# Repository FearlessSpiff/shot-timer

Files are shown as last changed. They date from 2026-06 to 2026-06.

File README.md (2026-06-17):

# shot-timer

Switch-controlled coffee shot timer for the Seeed XIAO nRF52840 with SSD1306 OLED display and deep sleep.

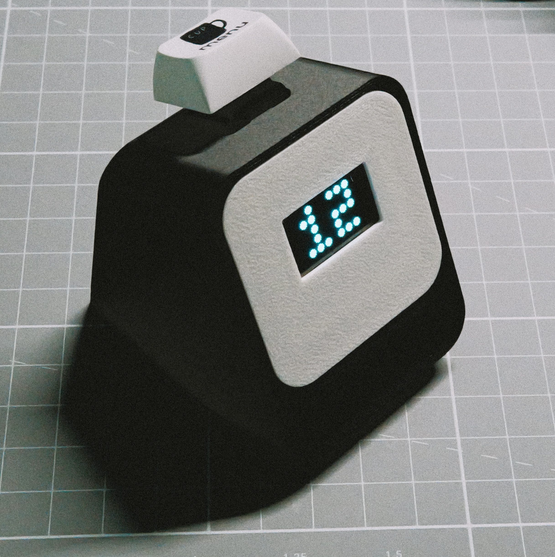
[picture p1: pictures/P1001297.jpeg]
Shot timer


## IMPORTANT

* Rotate case by 115.20 degrees in the slicer to have a nice front plate
* Rotate the backpanel by 79.8 degrees to make it sit flat on the bed

## Wiring

```
 Seeed XIAO nRF52840
 ┌─────────────────────┐
 │                 3V3 ├─────────────────── VCC ──┐
 │                 GND ├──────────┬──────── GND   ├── SSD1306
 │         D4 / (SDA)  ├──────────│──────── SDA   │    OLED
 │         D5 / (SCL)  ├──────────│──────── SCL ──┘
 │                  D1 ├───[ A ]  │
 │                BAT+ ├─────│────│──────────────── Battery +
 │                BAT- ├─────│────│──────────────── Battery -
 └─────────────────────┘     │    │
                             │    │
                          ┌──┴──┐ │
                          │ SW  │ │
                          └──┬──┘ │
                           [ B ]  │
                             └────┘ (GND)

 No external resistor needed — internal pull-up on D1 is enabled in firmware.
 Battery charges automatically when USB is connected.
```

| XIAO pin | Connects to |
|---|---|
| `3V3` | OLED VCC |
| `GND` | OLED GND, Switch Leg B |
| `D4 (SDA)` | OLED SDA |
| `D5 (SCL)` | OLED SCL |
| `D1` | Switch Leg A |
| `BAT+` | Battery positive |
| `BAT-` | Battery negative |

Most SSD1306 breakout boards label their pins `VCC GND SCL SDA` left-to-right — double check yours before wiring.

> [!WARNING]
> Use `3V3` for OLED power, **not** `VUSB`. VUSB is only live when USB is connected — the OLED will be dead on battery if wired to VUSB.

## Behaviour

| Action | Result |
|---|---|
| Short press (stopped) | Start timer |
| Short press (running) | Pause timer |
| Hold 1 s | Reset timer to 0 |
| Hold 3 s | Show battery percentage (2 s), then back to the timer |
| Timer reaches 99 s | Deep sleep |
| Paused / stopped for 60 s | Deep sleep |

Battery percentage is read from the XIAO nRF52840 Sense's onboard divider (`P0.14`/`VBAT_ENABLE` gates `P0.31`/`PIN_VBAT`) — no extra wiring needed beyond the `BAT+`/`BAT-` connection already shown above.

Press the switch to wake from deep sleep.

## Case

* The case has been adapted from <https://makerworld.com/en/models/1393341-desktop-wifi-informer-esp8266-oled-ssd1306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>
* Seeed XIAO BLE compatability has been added
* My SSD1306 has been made compatible to the front panel
* A hole has been added on top to take an MX switch

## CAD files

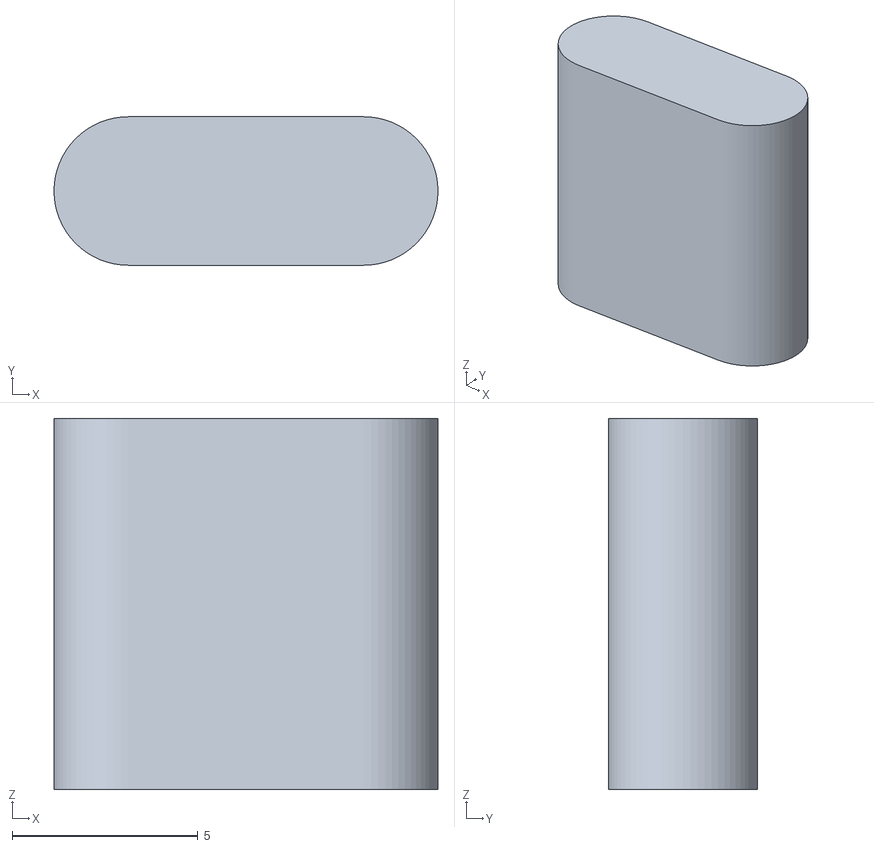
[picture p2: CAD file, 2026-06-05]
case/helper/usbc-cutout-gauge.stl
10.3 x 4.00 x 10.0

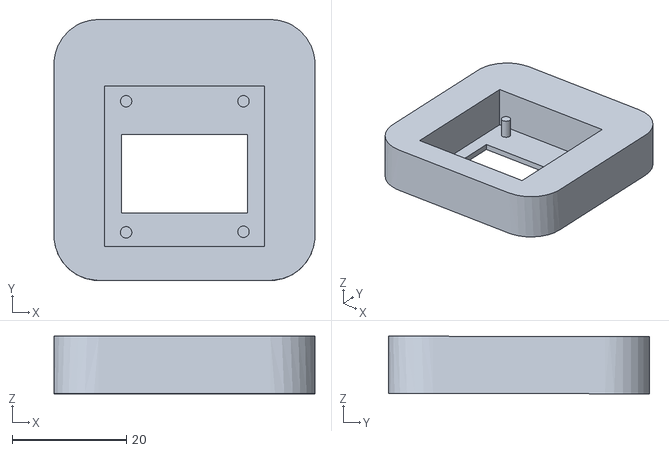
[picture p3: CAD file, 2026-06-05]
case/shot-timer-frontplate.stl
45.6 x 45.6 x 10.1

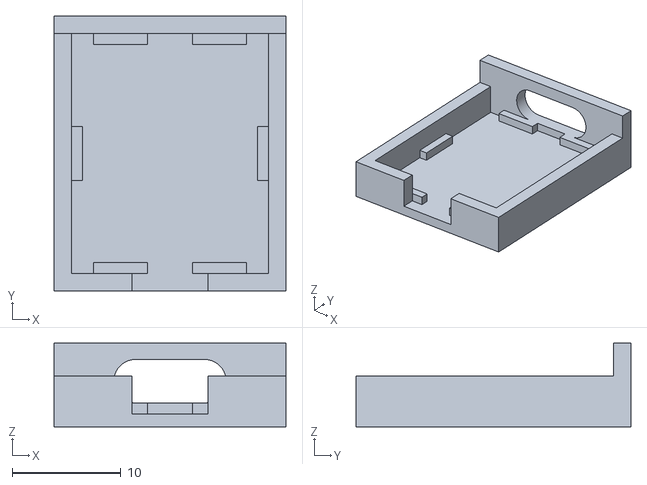
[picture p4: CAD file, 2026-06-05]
case/helper/xiao-tub.stl
21.3 x 25.3 x 7.70

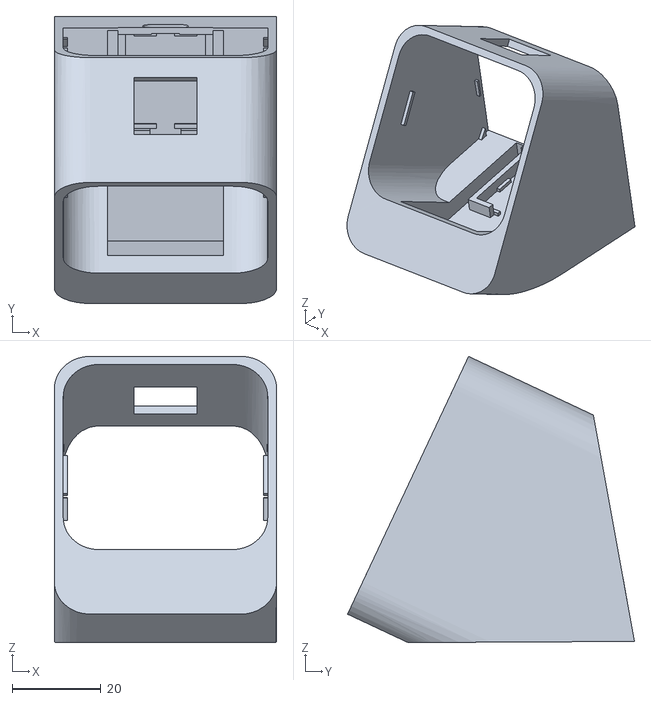
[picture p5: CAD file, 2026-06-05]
case/shot-timer-case.stl
50.0 x 64.5 x 64.4

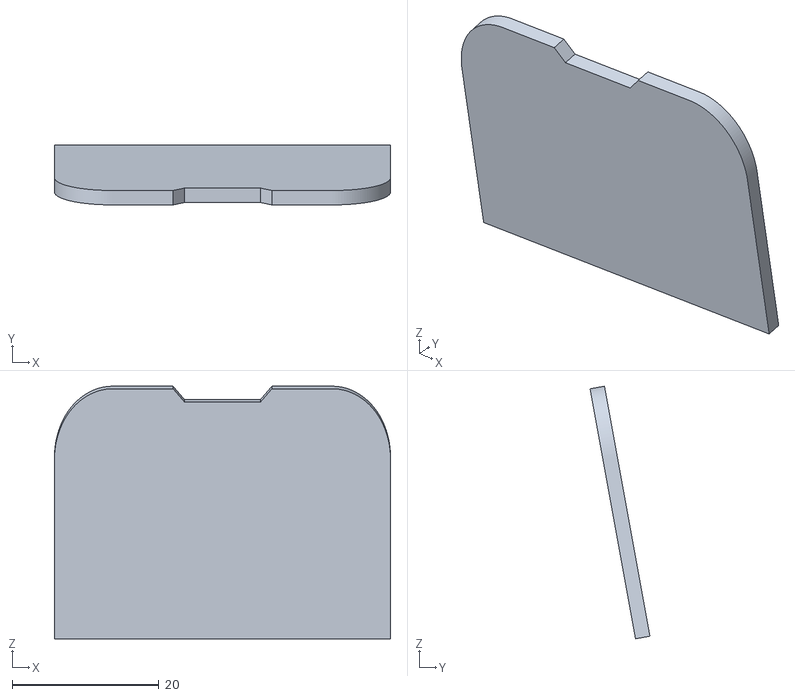
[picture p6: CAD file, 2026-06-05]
case/shot-timer-backplate.stl
45.8 x 8.16 x 34.4

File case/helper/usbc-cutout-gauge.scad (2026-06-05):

// ============================================================
//  USB-C Cutout Gauge
//  Matches the oval hole cut in xiao-tub.scad exactly.
//  Print this to verify the cutout fits your USB-C connector
//  before printing the full tub.
//
//  Dimensions (from xiao-tub.scad):
//    Width:  usbc_hole_w = 8.94 + 1.4 = 10.34 mm
//    Height: usbc_conn_h = 4.00 mm  (radius = 2.00 mm)
//    Shape:  stadium (hull of two circles)
// ============================================================

// Mirror of xiao-tub.scad values — keep in sync if tub changes
usbc_conn_w  = 8.94;
usbc_conn_h  = 4;
usbc_hole_r  = usbc_conn_h / 2;
usbc_hole_w  = usbc_conn_w + 1.4;

gauge_depth  = 10.0;   // extrusion thickness of the gauge

linear_extrude(height = gauge_depth)
    hull() {
        translate([ usbc_hole_w/2 - usbc_hole_r, 0])
            circle(r = usbc_hole_r, $fn = 64);
        translate([-(usbc_hole_w/2 - usbc_hole_r), 0])
            circle(r = usbc_hole_r, $fn = 64);
    }

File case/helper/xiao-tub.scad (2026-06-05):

// ============================================================
//  Seeed XIAO nRF52840 — MCU Tub / Cradle
//  Separate part to position freely alongside body.scad
//
//  Board dimensions (official):
//    PCB:       21.5 mm (L) × 17.5 mm (W) × 1.0 mm (thick)
//    Total H:   ~3.5 mm incl. components on top
//    USB-C:     on the +Y short end
//               connector body: 8.94 mm wide × 3.26 mm tall
//
//  Tub orientation:
//    X = width  (17.5 mm direction)
//    Y = length (21.5 mm, USB-C end at +Y)
//    Z = height (opens upward, board drops in from top)
// ============================================================

// --- Board dimensions ---
board_l       = 21.5;   // PCB length  (Y)
board_w       = 17.5;   // PCB width   (X)
board_h       = 1.0;    // PCB thickness
comp_h        = 2.5;    // tallest components above PCB (excl. USB-C)
tol           = 0.3;    // clearance around board on each side

// --- Tub wall & floor (defined early so other vars can use them) ---
wall          = 1.6;    // wall thickness
floor_t       = 1.2;    // floor thickness

// --- USB-C connector geometry ---
usbc_conn_w   = 8.94;              // connector width (IEC spec)
usbc_conn_h   = 4;             // connector height (typical SMD receptacle)
usbc_hole_r   = usbc_conn_h / 2;  // end radius fixed to connector height → keeps oval shape
usbc_hole_w   = usbc_conn_w + 1.4; // +1.4 mm total clearance
usbc_hole_h   = usbc_conn_h + 1.9; // +1.9 mm total clearance
// Z-center of connector measured from tub floor:
usbc_center_z = floor_t + board_h + usbc_conn_h / 2;
// Front wall height: floor + PCB + connector + 1.5 mm margin
front_wall_h  = floor_t + board_h + usbc_conn_h + 1.5;

// --- Battery solder cutout (-Y back wall) ---
batt_w        = 7.0;   // width — covers BAT+/BAT- pads
batt_h        = 3.5;   // height — clears PCB + some room
batt_z        = floor_t; // starts at tub floor level

// --- Derived internals ---
inner_l   = board_l + 2 * tol;
inner_w   = board_w + 2 * tol;
inner_h   = board_h + comp_h;

outer_l   = inner_l + 2 * wall;
outer_w   = inner_w + 2 * wall;
outer_h   = floor_t + inner_h;   // height of back/side walls (open top)

// --- Ledge parameters ---
ledge_t   = 1.0;   // protrusion into pocket
ledge_h   = board_h;
ledge_len = 5.0;
corner_gap = 2.0;

module xiao_tub() {
    difference() {
        union() {
            // Base box (back + side walls at normal height)
            cube([outer_w, outer_l, outer_h]);

            // Raised front wall (+Y) to enclose USB-C connector
            translate([0, outer_l - wall, 0])
                cube([outer_w, wall, front_wall_h]);
        }

        // --- Inner pocket ---
        translate([wall, wall, floor_t])
            cube([inner_w, inner_l, inner_h + 1]);

        // --- USB-C oval hole in raised front wall ---
        // rotate([90,0,0]) maps +Z → -Y, so starting at outer_l+1 cuts back through the wall
        translate([outer_w / 2, outer_l + 1, usbc_center_z])
            rotate([90, 0, 0])
                linear_extrude(height = wall + 3)
                    hull() {
                        translate([ usbc_hole_w/2 - usbc_hole_r, 0])
                            circle(r = usbc_hole_r, $fn = 64);
                        translate([-(usbc_hole_w/2 - usbc_hole_r), 0])
                            circle(r = usbc_hole_r, $fn = 64);
                    }

        // --- Battery solder cutout on -Y (back) wall ---
        translate([(outer_w - batt_w) / 2, -0.01, batt_z])
            cube([batt_w, wall + 2, batt_h]);
    }

    // --- Board retaining ledges (all four sides) ---
    // -Y wall (back) — two ledges either side of battery cutout
    translate([wall + corner_gap, wall, floor_t])
        cube([ledge_len, ledge_t, ledge_h]);
    translate([wall + inner_w - corner_gap - ledge_len, wall, floor_t])
        cube([ledge_len, ledge_t, ledge_h]);

    // +Y wall (front) — two ledges either side of USB-C hole
    translate([wall + corner_gap, wall + inner_l - ledge_t, floor_t])
        cube([ledge_len, ledge_t, ledge_h]);
    translate([wall + inner_w - corner_gap - ledge_len, wall + inner_l - ledge_t, floor_t])
        cube([ledge_len, ledge_t, ledge_h]);

    // -X wall (left) — one ledge centered
    translate([wall, wall + (inner_l - ledge_len) / 2, floor_t])
        cube([ledge_t, ledge_len, ledge_h]);

    // +X wall (right) — one ledge centered
    translate([wall + inner_w - ledge_t, wall + (inner_l - ledge_len) / 2, floor_t])
        cube([ledge_t, ledge_len, ledge_h]);
}

xiao_tub();

// ============================================================
//  Usage:
//    use <xiao_tub.scad>
//    translate([X,Y,Z]) rotate([RX,RY,RZ]) xiao_tub();
//
//  Key dimensions:
//    Outer (back/sides): outer_w × outer_l × outer_h  ≈ 21.7 × 25.3 × 4.7 mm
//    Front wall height:  front_wall_h                 ≈ 6.7 mm
//    Inner pocket:       inner_w × inner_l            ≈ 18.1 × 22.1 mm
//    USB-C hole:         9.34 × 3.66 mm oval, centered on connector
//    Battery cutout:     7.0 × 3.5 mm, centered, -Y wall
// ============================================================

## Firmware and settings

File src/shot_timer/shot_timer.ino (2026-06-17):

/**
 * shot_timer.ino
 * Seeed XIAO nRF52840 — Switch-controlled stopwatch with deep sleep
 *
 * Wiring:
 *   Switch leg A → D1 (P0.03)
 *   Switch leg B → GND
 *   (Internal pull-up enabled — no external resistor needed)
 *
 * Behaviour:
 *   Single press (while stopped) → Start timer
 *   Single press (while running) → Pause timer
 *   Hold 1 s                     → Reset timer to 0
 *   Hold 3 s                     → Show battery percentage
 *   Timer reaches 99 s           → Deep sleep
 *   Timer paused for > 60 s      → Deep sleep
 */

#include <Arduino.h>
#include <Adafruit_GFX.h>
#include <Adafruit_SSD1306.h>

// ── Pin ──────────────────────────────────────────────────────────────
#define SWITCH_PIN    1        // D1 / P0.03

// ── OLED ─────────────────────────────────────────────────────────────
#define OLED_WIDTH   128
#define OLED_HEIGHT   64
#define OLED_RESET    -1
#define OLED_ADDRESS  0x3C

Adafruit_SSD1306 oled(OLED_WIDTH, OLED_HEIGHT, &Wire, OLED_RESET);

// ── Config ───────────────────────────────────────────────────────────
#define SHOW_SPLASH         1    // 1 = show coffee bean splash on boot, 0 = skip

// ── Timing constants ─────────────────────────────────────────────────
#define DEBOUNCE_MS         20
#define HOLD_RESET_MS     1000   // hold duration to trigger reset
#define HOLD_BATTERY_MS   3000   // hold duration to show battery percentage
#define DISPLAY_INTERVAL_MS 1000 // display update interval while running
#define MAX_SECONDS         60   // sleep when timer hits this
#define IDLE_SLEEP_MS    60000UL // sleep if paused/stopped for this long
#define BATTERY_DISPLAY_MS 2000  // how long the battery % stays on screen

// ── Battery (XIAO nRF52840 Sense onboard divider — P0.14 / P0.31) ────
// VBAT_ENABLE and PIN_VBAT are provided by the board variant.
#define VBAT_DIVIDER_RATIO (1510.0f / 510.0f)  // onboard divider ratio
#define VBAT_MV_PER_LSB    (0.003395996f)      // 10-bit ADC, ~3.6V internal ref
#define VBAT_MIN_V         3.0f                // maps to 0%
#define VBAT_MAX_V         4.2f                // maps to 100%

// ── State machine ─────────────────────────────────────────────────────
enum TimerState { STOPPED, RUNNING, PAUSED };
TimerState timerState = STOPPED;

// ── Counters & timestamps ─────────────────────────────────────────────
uint32_t elapsedSeconds  = 0;
uint32_t runStartMs      = 0;
uint32_t lastDisplayMs   = 0;
uint32_t idleStartMs     = 0;

// ── Coffee bean splash bitmap (64×64, centred on 128×64 display) ─────
static const uint8_t COFFEE_BITMAP[] = {
  0x00, 0x00, 0x00, 0x00, 0x00, 0x00, 0x00, 0x00,
  0x00, 0x00, 0x00, 0x00, 0x00, 0x00, 0x00, 0x00,
  0x00, 0x00, 0x00, 0x00, 0x00, 0x00, 0x00, 0x00,
  0x00, 0x00, 0x00, 0x00, 0x00, 0x00, 0x00, 0x00,
  0x00, 0x00, 0x00, 0x00, 0x00, 0x00, 0x00, 0x00,
  0x00, 0x00, 0x00, 0x00, 0x00, 0x00, 0x00, 0x00,
  0x00, 0x00, 0x00, 0x00, 0x00, 0x00, 0x00, 0x00,
  0x00, 0x00, 0x00, 0x00, 0x00, 0x00, 0x00, 0x00,
  0x00, 0x00, 0x00, 0x00, 0x00, 0x00, 0x00, 0x00,
  0x00, 0x00, 0x00, 0x00, 0x00, 0x00, 0x00, 0x00,
  0x00, 0x00, 0x00, 0x7F, 0x00, 0x00, 0x00, 0x00,
  0x00, 0x00, 0x01, 0xFF, 0xF0, 0x00, 0x00, 0x00,
  0x00, 0x00, 0x07, 0xFF, 0xFC, 0x00, 0x00, 0x00,
  0x00, 0x00, 0x03, 0xFF, 0xFF, 0x00, 0x00, 0x00,
  0x00, 0x00, 0x01, 0xFF, 0xFF, 0x80, 0x00, 0x00,
  0x00, 0x00, 0x10, 0xFF, 0xFF, 0xC0, 0x00, 0x00,
  0x00, 0x00, 0x18, 0x7F, 0xFF, 0xE0, 0x00, 0x00,
  0x00, 0x00, 0x1C, 0x3F, 0xFF, 0xF0, 0x00, 0x00,
  0x00, 0x00, 0x1F, 0x03, 0xFF, 0xF8, 0x00, 0x00,
  0x00, 0x00, 0x1F, 0x80, 0x07, 0xF8, 0x00, 0x00,
  0x00, 0x00, 0x1F, 0xE0, 0x01, 0xFC, 0x00, 0x00,
  0x00, 0x00, 0x0F, 0xFF, 0xF0, 0x7C, 0x00, 0x00,
  0x00, 0x00, 0x0F, 0xFF, 0xFC, 0x3C, 0x00, 0x00,
  0x00, 0x00, 0x07, 0xFF, 0xFF, 0x1C, 0x00, 0x00,
  0x00, 0x00, 0x03, 0xFF, 0xFF, 0x8C, 0x00, 0x00,
  0x00, 0x00, 0x01, 0xFF, 0xFF, 0xC0, 0x00, 0x00,
  0x00, 0x3F, 0xC0, 0xFF, 0xFF, 0xE0, 0x00, 0x00,
  0x00, 0x1F, 0xF0, 0x7F, 0xFF, 0xF0, 0x00, 0x00,
  0x00, 0x0F, 0xFC, 0x1F, 0xFF, 0xE0, 0x00, 0x00,
  0x00, 0x83, 0xFE, 0x03, 0xFF, 0x80, 0x00, 0x00,
  0x01, 0xE1, 0xFF, 0x00, 0x18, 0x00, 0x00, 0x00,
  0x01, 0xF0, 0xFF, 0x80, 0x00, 0x03, 0xF0, 0x00,
  0x01, 0xF8, 0x7F, 0x80, 0x00, 0x1F, 0xF8, 0x00,
  0x01, 0xFC, 0x7F, 0xC0, 0x00, 0x7F, 0xF8, 0x00,
  0x01, 0xFE, 0x3F, 0xE0, 0x01, 0xFF, 0xF1, 0x00,
  0x01, 0xFE, 0x3F, 0xE0, 0x03, 0xFF, 0xF1, 0x80,
  0x01, 0xFF, 0x3F, 0xF0, 0x07, 0xFF, 0xE3, 0x80,
  0x01, 0xFF, 0x3F, 0xF0, 0x0F, 0xFF, 0xC7, 0x80,
  0x00, 0xFF, 0x1F, 0xF0, 0x1F, 0xFF, 0xC7, 0x80,
  0x00, 0xFF, 0x9F, 0xF0, 0x3F, 0xFF, 0x8F, 0x80,
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
};

// ── Forward declarations ──────────────────────────────────────────────
void updateDisplay();

// ── Switch state ──────────────────────────────────────────────────────
bool     lastSwitchPhysical = HIGH;
bool     switchPressed      = false;
bool     switchHeld         = false;
bool     batteryShown       = false;
bool     buttonDown         = false;
uint32_t pressStartMs       = 0;

// ─────────────────────────────────────────────────────────────────────
// Deep sleep — wakes on switch press (falling edge on pin D1)
// ─────────────────────────────────────────────────────────────────────
void goToDeepSleep() {
  oled.ssd1306_command(SSD1306_DISPLAYOFF);

  // Wait for the switch to be released before arming GPIO SENSE —
  // otherwise the pin is already LOW and the chip wakes immediately.
  pinMode(SWITCH_PIN, INPUT_PULLUP);
  while (digitalRead(SWITCH_PIN) == LOW) {}
  delay(200);  // debounce

#ifdef NRF52_SERIES
  attachInterrupt(digitalPinToInterrupt(SWITCH_PIN), [](){}, FALLING);
  nrf_gpio_cfg_sense_input(
      g_ADigitalPinMap[SWITCH_PIN],
      NRF_GPIO_PIN_PULLUP,
      NRF_GPIO_PIN_SENSE_LOW);
  sd_power_system_off();
  NRF_POWER->SYSTEMOFF = 1;
  while (true) {}
#else
  while (true) { delay(1000); }
#endif
}

// ─────────────────────────────────────────────────────────────────────
// Reset the timer (does not change run state)
// ─────────────────────────────────────────────────────────────────────
void resetTimer() {
  elapsedSeconds = 0;
  runStartMs     = millis();
  lastDisplayMs  = millis();
  idleStartMs    = millis();
  updateDisplay();
}

// ─────────────────────────────────────────────────────────────────────
// Current total seconds (elapsed + in-progress segment)
// ─────────────────────────────────────────────────────────────────────
uint32_t currentSeconds() {
  if (timerState == RUNNING) {
    return elapsedSeconds + (millis() - runStartMs) / 1000;
  }
  return elapsedSeconds;
}

// ─────────────────────────────────────────────────────────────────────
// 3×5 dot-matrix font
// Each row byte: bit 2 = left col, bit 1 = mid col, bit 0 = right col
// ─────────────────────────────────────────────────────────────────────
#define DOT_PITCH   12   // dot center-to-center (px)
#define DOT_RADIUS   4   // dot radius (px)
#define CHAR_GAP    12   // gap between characters (px) — matches DOT_PITCH

static const uint8_t DOT_GLYPHS[10][5] = {
  {0b111, 0b101, 0b101, 0b101, 0b111},  // 0
  {0b010, 0b110, 0b010, 0b010, 0b111},  // 1
  {0b111, 0b001, 0b111, 0b100, 0b111},  // 2
  {0b111, 0b001, 0b111, 0b001, 0b111},  // 3
  {0b101, 0b101, 0b111, 0b001, 0b001},  // 4
  {0b111, 0b100, 0b111, 0b001, 0b111},  // 5
  {0b111, 0b100, 0b111, 0b101, 0b111},  // 6
  {0b111, 0b001, 0b001, 0b001, 0b001},  // 7
  {0b111, 0b101, 0b111, 0b101, 0b111},  // 8
  {0b111, 0b101, 0b111, 0b001, 0b111},  // 9
};

void drawDotChar(int16_t x0, int16_t y0, uint8_t digit) {
  for (uint8_t row = 0; row < 5; row++) {
    uint8_t bits = DOT_GLYPHS[digit][row];
    for (uint8_t col = 0; col < 3; col++) {
      if (bits & (4 >> col)) {
        oled.fillCircle(x0 + col * DOT_PITCH, y0 + row * DOT_PITCH,
                        DOT_RADIUS, SSD1306_WHITE);
      }
    }
  }
}

// ─────────────────────────────────────────────────────────────────────
// Draw a 0-99 number as dot-matrix digits, centered on the OLED.
// withPercent shifts the digits left and adds a small "%" to the right.
// ─────────────────────────────────────────────────────────────────────
void drawDotNumber(uint32_t value, bool withPercent) {
  if (value > 99) value = 99;

  const int16_t charW  = 2 * DOT_PITCH + 2 * DOT_RADIUS;  // 32 px
  const int16_t charH  = 4 * DOT_PITCH + 2 * DOT_RADIUS;  // 56 px
  const int16_t totalW = 2 * charW + CHAR_GAP;             // fixed 2-digit width

  int16_t x0 = (OLED_WIDTH  - totalW) / 2 + DOT_RADIUS;
  int16_t y0 = (OLED_HEIGHT - charH)  / 2 + DOT_RADIUS;

  if (withPercent) x0 -= 14;  // make room for the "%" sign on the right

  if (value >= 10) {
    drawDotChar(x0,                    y0, value / 10);
    drawDotChar(x0 + charW + CHAR_GAP, y0, value % 10);
  } else {
    drawDotChar(x0 + charW + CHAR_GAP, y0, value);  // units slot only
  }

  if (withPercent) {
    oled.setTextSize(2);
    oled.setTextColor(SSD1306_WHITE);
    oled.setCursor(x0 + 2 * charW + CHAR_GAP + DOT_RADIUS + 4, (OLED_HEIGHT - 16) / 2);
    oled.print(F("%"));
  }
}

// ─────────────────────────────────────────────────────────────────────
// Render seconds as dot-matrix digits centered on the OLED
// ─────────────────────────────────────────────────────────────────────
void updateDisplay() {
  oled.clearDisplay();
  drawDotNumber(currentSeconds(), false);
  oled.display();
}

// ─────────────────────────────────────────────────────────────────────
// Battery — read via the XIAO nRF52840 Sense's onboard divider
// (P0.14 / VBAT_ENABLE gates P0.31 / PIN_VBAT to ~1/3 of battery voltage)
// ─────────────────────────────────────────────────────────────────────
float readBatteryVoltage() {
  digitalWrite(VBAT_ENABLE, LOW);   // enable divider
  delay(10);                        // let it settle
  uint32_t raw = analogRead(PIN_VBAT);
  digitalWrite(VBAT_ENABLE, HIGH);  // disable again to save sleep current
  return raw * VBAT_MV_PER_LSB * VBAT_DIVIDER_RATIO;
}

uint8_t batteryPercent() {
  float pct = (readBatteryVoltage() - VBAT_MIN_V) / (VBAT_MAX_V - VBAT_MIN_V) * 100.0f;
  if (pct < 0)  pct = 0;
  if (pct > 99) pct = 99;  // keep it to 2 digits for the dot-matrix display
  return (uint8_t)(pct + 0.5f);
}

void showBatteryPercent() {
  oled.clearDisplay();
  drawDotNumber(batteryPercent(), true);
  oled.display();
  delay(BATTERY_DISPLAY_MS);
  updateDisplay();  // back to the timer view
}

// ─────────────────────────────────────────────────────────────────────
// 1-second splash screen
// ─────────────────────────────────────────────────────────────────────
void showSplash() {
  oled.clearDisplay();
  // 64×64 bitmap centred horizontally on the 128×64 display
  oled.drawBitmap((OLED_WIDTH - 64) / 2, 0, COFFEE_BITMAP, 64, 64, SSD1306_WHITE);
  oled.display();
  delay(1500);
}

// ─────────────────────────────────────────────────────────────────────
// Setup
// ─────────────────────────────────────────────────────────────────────
void setup() {
  pinMode(SWITCH_PIN, INPUT_PULLUP);

  pinMode(VBAT_ENABLE, OUTPUT);
  digitalWrite(VBAT_ENABLE, HIGH);  // keep divider disabled until a reading is needed

  oled.begin(SSD1306_SWITCHCAPVCC, OLED_ADDRESS);

#if SHOW_SPLASH
  showSplash();
#endif

  idleStartMs = millis();
  updateDisplay();
}

// ─────────────────────────────────────────────────────────────────────
// Loop
// ─────────────────────────────────────────────────────────────────────
void loop() {
  // ── 1. Read & debounce switch ──────────────────────────────────────
  bool raw = digitalRead(SWITCH_PIN);

  if (raw == LOW && lastSwitchPhysical == HIGH) {
    delay(DEBOUNCE_MS);
    if (digitalRead(SWITCH_PIN) == LOW) {
      pressStartMs = millis();
      switchHeld   = false;
      buttonDown   = true;
    }
  }

  if (raw == HIGH && lastSwitchPhysical == LOW) {
    delay(DEBOUNCE_MS);
    if (digitalRead(SWITCH_PIN) == HIGH) {
      buttonDown  = false;
      if (!switchHeld) {
        switchPressed = true;
      }
      switchHeld    = false;
      batteryShown  = false;
    }
  }

  if (buttonDown) {
    uint32_t heldMs = millis() - pressStartMs;
    if (!switchHeld && heldMs >= HOLD_RESET_MS) {
      switchHeld = true;
      timerState = STOPPED;
      resetTimer();
    }
    if (switchHeld && !batteryShown && heldMs >= HOLD_BATTERY_MS) {
      batteryShown = true;
      showBatteryPercent();
    }
  }

  lastSwitchPhysical = raw;

  // ── 2. Handle short-press events ──────────────────────────────────
  if (switchPressed) {
    switchPressed = false;

    switch (timerState) {
      case STOPPED:
      case PAUSED:
        timerState    = RUNNING;
        runStartMs    = millis();
        lastDisplayMs = millis();
        updateDisplay();
        break;

      case RUNNING:
        elapsedSeconds = currentSeconds();
        timerState     = PAUSED;
        idleStartMs    = millis();
        updateDisplay();
        break;
    }
  }

  // ── 3. Periodic display update while running ───────────────────────
  if (timerState == RUNNING) {
    if ((millis() - lastDisplayMs) >= DISPLAY_INTERVAL_MS) {
      lastDisplayMs = millis();
      updateDisplay();

      if (currentSeconds() >= MAX_SECONDS) {
        goToDeepSleep();
      }
    }
  }

  // ── 4. Idle timeout (stopped or paused with no activity) ──────────
  if (timerState == STOPPED || timerState == PAUSED) {
    if ((millis() - idleStartMs) >= IDLE_SLEEP_MS) {
      goToDeepSleep();
    }
  }
}

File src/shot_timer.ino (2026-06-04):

/**
 * shot_timer.ino
 * Seeed XIAO nRF52840 — Switch-controlled stopwatch with deep sleep
 *
 * Wiring:
 *   Switch leg A → D1 (P0.03)
 *   Switch leg B → GND
 *   (Internal pull-up enabled — no external resistor needed)
 *
 * Behaviour:
 *   Single press (while stopped) → Start timer
 *   Single press (while running) → Pause timer
 *   Hold 2 s                     → Reset timer to 0
 *   Timer reaches 99 s           → Deep sleep
 *   Timer paused for > 60 s      → Deep sleep
 */

#include <Arduino.h>

// ── Pin ──────────────────────────────────────────────────────────────
#define SWITCH_PIN  1          // D1 / P0.03

// ── Timing constants ─────────────────────────────────────────────────
#define DEBOUNCE_MS         20
#define HOLD_RESET_MS     2000   // hold duration to trigger reset
#define LOG_INTERVAL_MS   1000   // log every second
#define MAX_SECONDS         99   // sleep when timer hits this
#define IDLE_SLEEP_MS    60000UL // sleep if paused/stopped for this long

// ── State machine ─────────────────────────────────────────────────────
enum TimerState { STOPPED, RUNNING, PAUSED };
TimerState timerState = STOPPED;

// ── Counters & timestamps ─────────────────────────────────────────────
uint32_t elapsedSeconds  = 0;    // accumulated full seconds
uint32_t runStartMs      = 0;    // millis() when last run segment started
uint32_t lastLogMs       = 0;    // millis() of last 1-second log
uint32_t idleStartMs     = 0;    // millis() when we entered idle (stopped/paused)

// ── Switch state ──────────────────────────────────────────────────────
bool     lastSwitchPhysical = HIGH;  // raw pin state last loop
bool     switchPressed      = false; // debounced, one-shot press event
bool     switchHeld         = false; // true once hold threshold passed
uint32_t pressStartMs       = 0;     // when the current press began

// ─────────────────────────────────────────────────────────────────────
// Deep sleep — wakes on switch press (falling edge on pin D1)
// ─────────────────────────────────────────────────────────────────────
void goToDeepSleep(const char* reason) {
  Serial.print("[SLEEP] Reason: ");
  Serial.println(reason);
  Serial.flush();
  delay(10);

  // Configure the switch pin as a wake source (active-low)
  pinMode(SWITCH_PIN, INPUT_PULLUP);

  // nRF52840: use the Adafruit/Seeed BSP sleep helper
  // sd_power_system_off() puts the chip into System OFF (deepest sleep).
  // GPIO SENSE will restart execution from the reset vector on wake.
#ifdef NRF52_SERIES
  // Attach a dummy interrupt so the SENSE register is armed
  attachInterrupt(digitalPinToInterrupt(SWITCH_PIN), [](){}, FALLING);
  nrf_gpio_cfg_sense_input(
      g_ADigitalPinMap[SWITCH_PIN],
      NRF_GPIO_PIN_PULLUP,
      NRF_GPIO_PIN_SENSE_LOW);
  sd_power_system_off();   // does not return; chip resets on wake
#else
  // Fallback for simulation / other targets: busy-wait
  while (true) { delay(1000); }
#endif
}

// ─────────────────────────────────────────────────────────────────────
// Reset the timer (does not change run state)
// ─────────────────────────────────────────────────────────────────────
void resetTimer() {
  elapsedSeconds = 0;
  runStartMs     = millis();
  lastLogMs      = millis();
  idleStartMs    = millis();
  Serial.println("[RESET] Timer reset to 0");
}

// ─────────────────────────────────────────────────────────────────────
// Current total seconds (elapsed + in-progress segment)
// ─────────────────────────────────────────────────────────────────────
uint32_t currentSeconds() {
  if (timerState == RUNNING) {
    return elapsedSeconds + (millis() - runStartMs) / 1000;
  }
  return elapsedSeconds;
}

// ─────────────────────────────────────────────────────────────────────
// Setup
// ─────────────────────────────────────────────────────────────────────
void setup() {
  Serial.begin(115200);
  while (!Serial && millis() < 3000) {}  // wait up to 3 s for USB

  pinMode(SWITCH_PIN, INPUT_PULLUP);

  Serial.println("=== Switch Timer Ready ===");
  Serial.println("  Short press → start / pause");
  Serial.println("  Hold 2 s   → reset");
  Serial.println("  Limit: 99 s or 60 s idle → deep sleep");

  idleStartMs = millis();
}

// ─────────────────────────────────────────────────────────────────────
// Loop
// ─────────────────────────────────────────────────────────────────────
void loop() {
  uint32_t now = millis();

  // ── 1. Read & debounce switch ──────────────────────────────────────
  bool raw = digitalRead(SWITCH_PIN);

  if (raw == LOW && lastSwitchPhysical == HIGH) {
    // Falling edge — start debounce window
    delay(DEBOUNCE_MS);
    if (digitalRead(SWITCH_PIN) == LOW) {
      // Confirmed press
      pressStartMs   = millis();
      switchHeld     = false;
    }
  }

  if (raw == HIGH && lastSwitchPhysical == LOW) {
    // Rising edge — button released
    delay(DEBOUNCE_MS);
    if (digitalRead(SWITCH_PIN) == HIGH) {
      if (!switchHeld) {
        // Short press: not a hold-reset, fire the press event
        switchPressed = true;
      }
      switchHeld = false;
    }
  }

  // Detect hold threshold while button is still down
  if (raw == LOW && !switchHeld) {
    if ((millis() - pressStartMs) >= HOLD_RESET_MS) {
      switchHeld = true;
      // ── Hold action: reset ──
      timerState = STOPPED;
      resetTimer();
    }
  }

  lastSwitchPhysical = raw;

  // ── 2. Handle short-press events ──────────────────────────────────
  if (switchPressed) {
    switchPressed = false;

    switch (timerState) {
      case STOPPED:
      case PAUSED:
        // Start / resume
        timerState  = RUNNING;
        runStartMs  = millis();
        lastLogMs   = millis();
        Serial.println(timerState == RUNNING
                       ? "[START] Timer running"
                       : "[RESUME] Timer resumed");
        // Print immediately so the state change is visible
        Serial.print("[TIME] ");
        Serial.print(currentSeconds());
        Serial.println(" s");
        break;

      case RUNNING:
        // Pause — freeze elapsed seconds
        elapsedSeconds = currentSeconds();
        timerState     = PAUSED;
        idleStartMs    = millis();
        Serial.print("[PAUSE] Paused at ");
        Serial.print(elapsedSeconds);
        Serial.println(" s");
        break;
    }
  }

  // ── 3. Periodic 1-second log while running ─────────────────────────
  if (timerState == RUNNING) {
    uint32_t secs = currentSeconds();

    if ((millis() - lastLogMs) >= LOG_INTERVAL_MS) {
      lastLogMs = millis();
      Serial.print("[TIME] ");
      Serial.print(secs);
      Serial.println(" s");

      // Check 99-second ceiling
      if (secs >= MAX_SECONDS) {
        Serial.print("[LIMIT] Reached ");
        Serial.print(MAX_SECONDS);
        Serial.println(" s");
        goToDeepSleep("99 s limit reached");
      }
    }
  }
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

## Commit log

2026-06-04 fix sleep, bugs and arduino studio compatibility
    [shot_timer.ino]
2026-06-05 add 3d printable stls
    [shot-timer-backplate.stl, shot-timer-case.stl, shot-timer-frontplate.stl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]
2026-06-05 add battery to readme and print hints
2026-06-05 add bit thicker front panel so that the OLED PCB cannot be seen when printing in white
    [shot-timer-frontplate.stl]
2026-06-17 Show battery percentage when long pressing
